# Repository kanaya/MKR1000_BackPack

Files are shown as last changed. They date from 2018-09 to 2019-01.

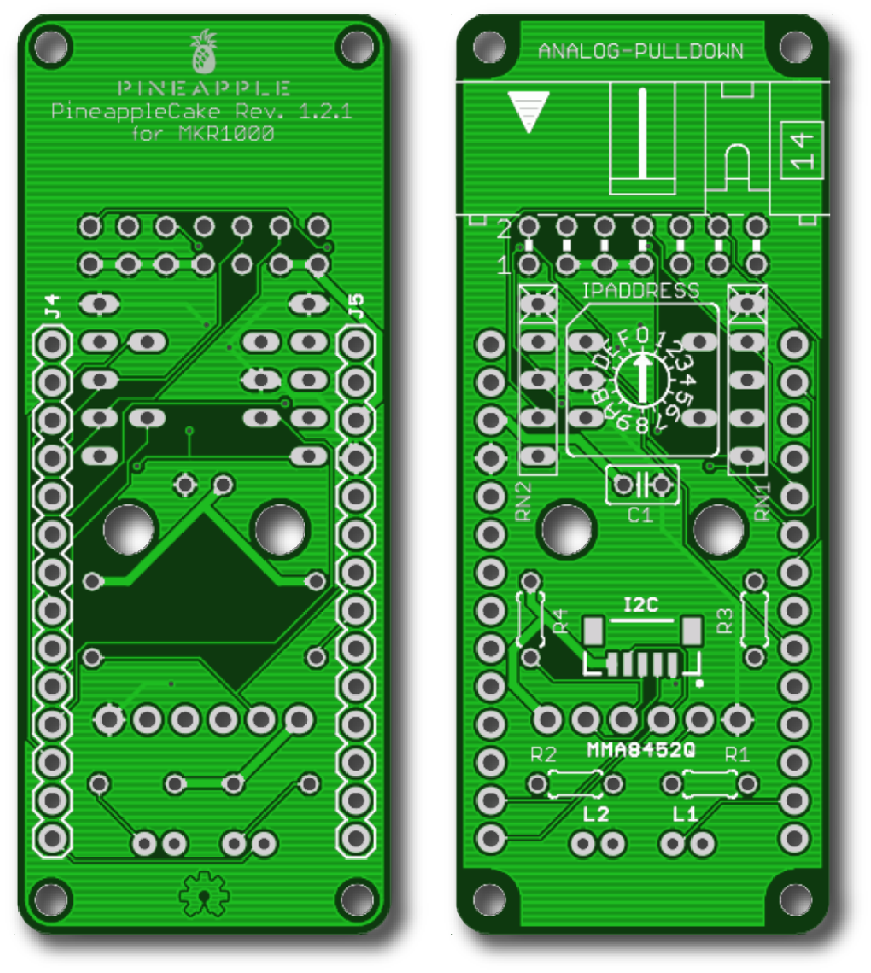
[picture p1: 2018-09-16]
doc/image/PineappleCake_1_2_1_material/5-PineappleCake_1_2_1_shadow.png

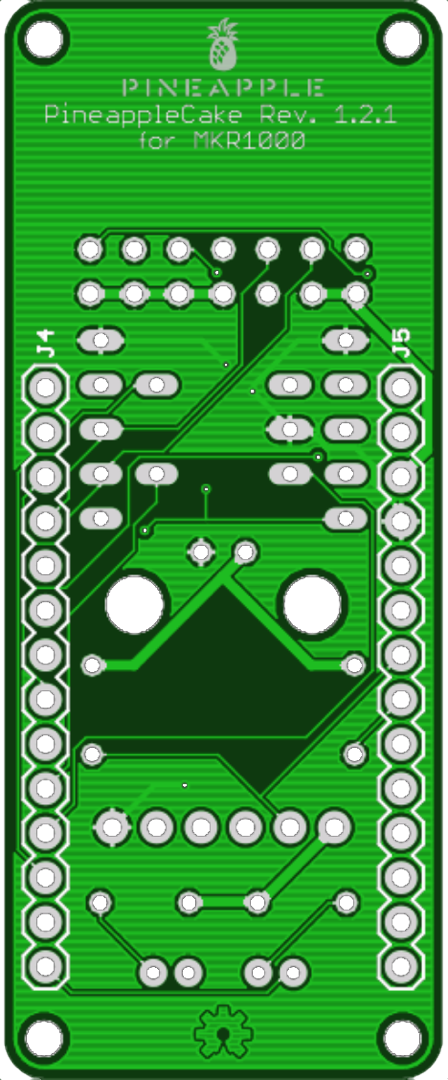
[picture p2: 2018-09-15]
doc/image/PineappleCake_1_2_1_material/3-PineappleCake_1_2_1-HD.png

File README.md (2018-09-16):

# PineappleCake

PineappleCake is a set of add-on board and software for [Arduino MKR1000](https://store.arduino.cc/usa/arduino-mkr1000) series for attaching analog sensors. Coupled with MKR1000, PineappleCake can read up-to seven physical sensors and send the values via HTTP on WiFi.

You can also attach [triple-axis accelerometer](https://www.sparkfun.com/products/12756) on PineappleCake. The acceleration data can be accessible via wireless HTTP connection.

And one more thing, you can control a couple of LEDs also via wireless HTTP connection.

You can change the IP address of multiple PineappleCakes by using attached rotary switch so that you’ll never need to modify the source code for just changing the addresses.

PineappleCake also offers missing [I2C connector (+5V, D7, SCL, SDA, GND)](https://store.arduino.cc/usa/arduino-mkrzero) found in other MKR series (e.g. [MKR ZERO](https://store.arduino.cc/usa/arduino-mkrzero)).

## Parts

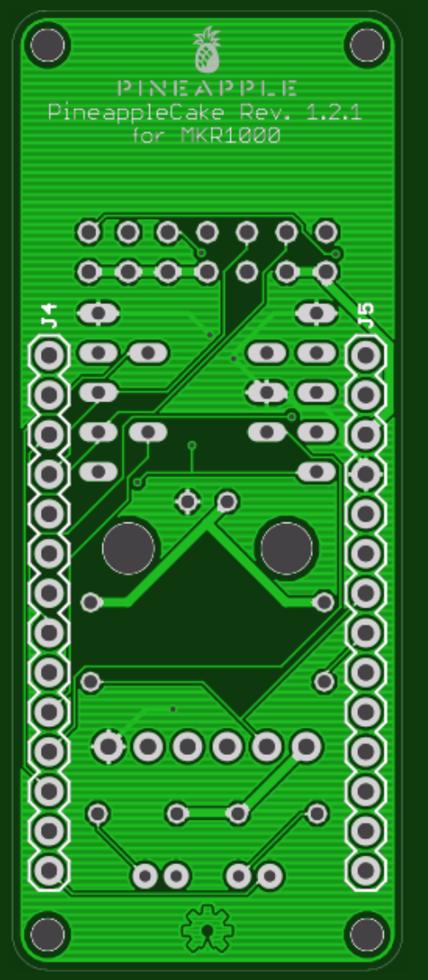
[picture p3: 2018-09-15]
doc/image/PineappleCake_1_2_1_material/0-PineappleCake_1_2_1_screenshot.png

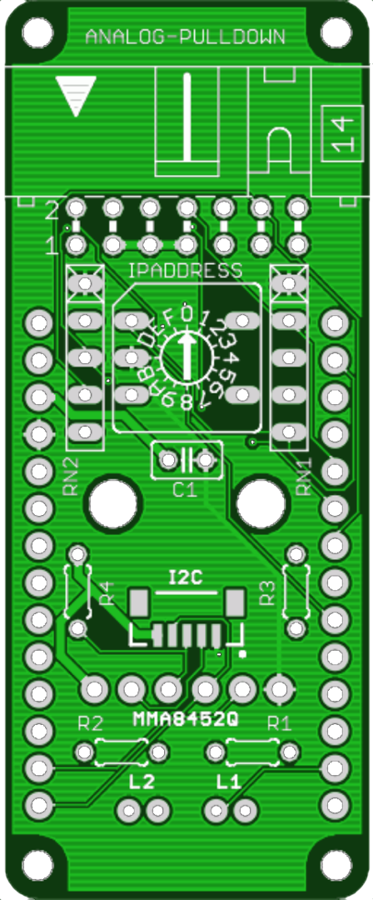
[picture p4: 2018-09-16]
doc/image/PineappleCake_1_2_1_back_material/3-PineappleCake_1_2_1_back-HD.png

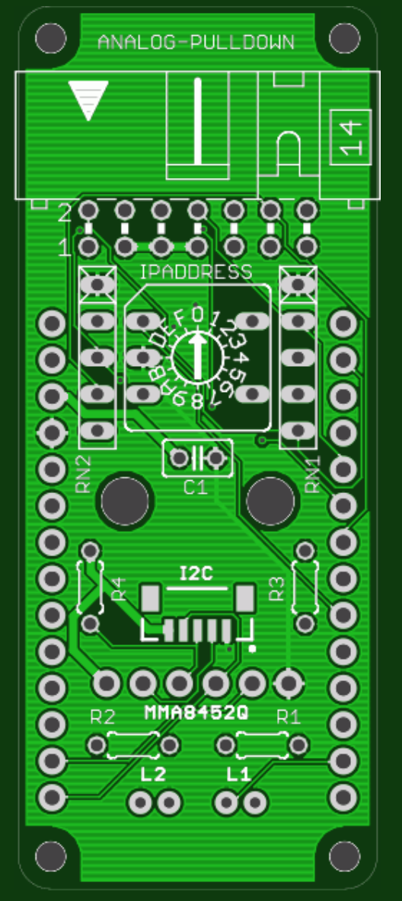
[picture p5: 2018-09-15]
doc/image/PineappleCake_1_2_1_back_material/0-PineappleCake_1_2_1_back_screenshot.png

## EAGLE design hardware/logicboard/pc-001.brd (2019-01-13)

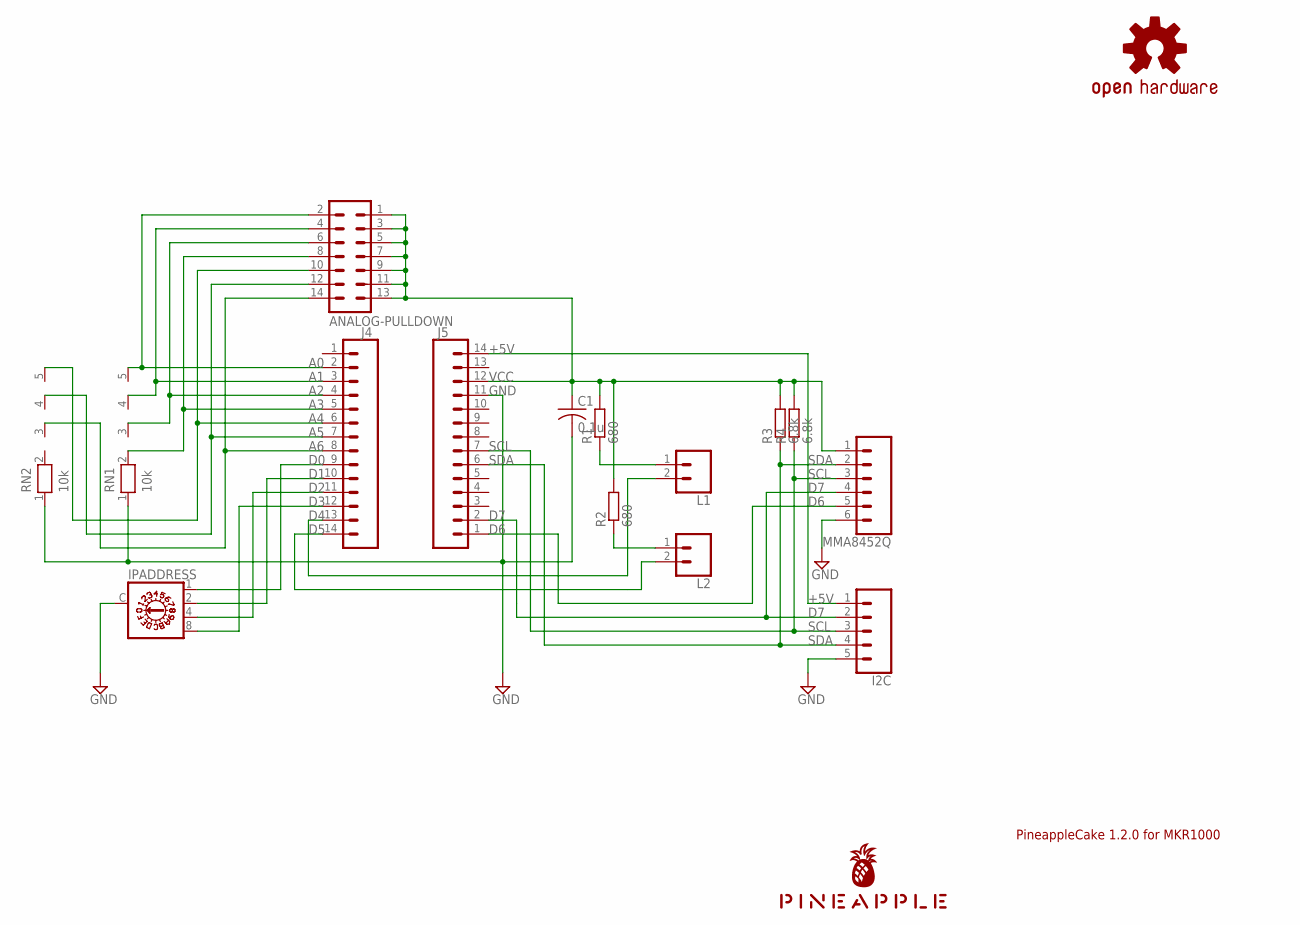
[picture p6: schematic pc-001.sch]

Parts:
ANALOG-PULLDOWN: ML14L
C1: 0.1u; C025-025X050
I2C: CONN_05SMD; 1X05_1MM
IPADDRESS: A1353HEX
J4, J5: DNP; 1X14
L1, L2: CONN_02-JST-2-PTH-NO_SILK; JST-2-PTH-NS
LOGO1: OSHW-LOGOS-COPPER; OSHW-LOGO-S_COPPER
MMA8452Q: CONN_06NO_SILK_FEMALE_PTH; 1X06_NO_SILK
R1, R2: 680; 0204/5
R3, R4: 6.8k; 0204/5
RN1, RN2: 10k; RN-5
U$1: PINEAPPLE450

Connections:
+5V: I2C.1, J5.14
A0: ANALOG-PULLDOWN.2, J4.2, RN1.5
A1: ANALOG-PULLDOWN.4, J4.3, RN1.4
A2: ANALOG-PULLDOWN.6, J4.4, RN1.3
A3: ANALOG-PULLDOWN.8, J4.5, RN1.2
A4: ANALOG-PULLDOWN.10, J4.6, RN2.5
A5: ANALOG-PULLDOWN.12, J4.7, RN2.4
A6: ANALOG-PULLDOWN.14, J4.8, RN2.3
D0: IPADDRESS.1, J4.9
D1: IPADDRESS.2, J4.10
D2: IPADDRESS.4, J4.11
D3: IPADDRESS.8, J4.12
D4: J4.13, L1.2
D5: J4.14, L2.2
D6: J5.1, MMA8452Q.5
D7: I2C.2, J5.2, MMA8452Q.4
GND: C1.2, I2C.5, IPADDRESS.C, J5.11, MMA8452Q.6, RN1.1, RN2.1
LED1A: L1.1, R1.1
LED2A: L2.1, R2.1
SCL: I2C.3, J5.7, MMA8452Q.3, R4.1
SDA: I2C.4, J5.6, MMA8452Q.2, R3.1
VCC: ANALOG-PULLDOWN.1, ANALOG-PULLDOWN.3, ANALOG-PULLDOWN.5, ANALOG-PULLDOWN.7, ANALOG-PULLDOWN.9, ANALOG-PULLDOWN.11, ANALOG-PULLDOWN.13, C1.1, J5.12, MMA8452Q.1, R1.2, R2.2, R3.2, R4.2

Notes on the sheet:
PineappleCake 1.2.0 for MKR1000

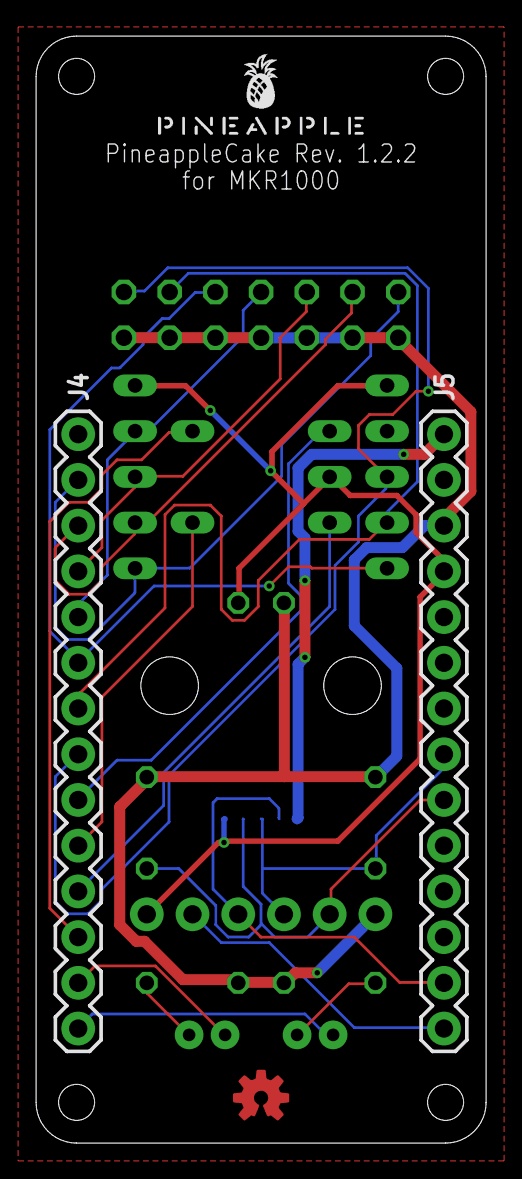
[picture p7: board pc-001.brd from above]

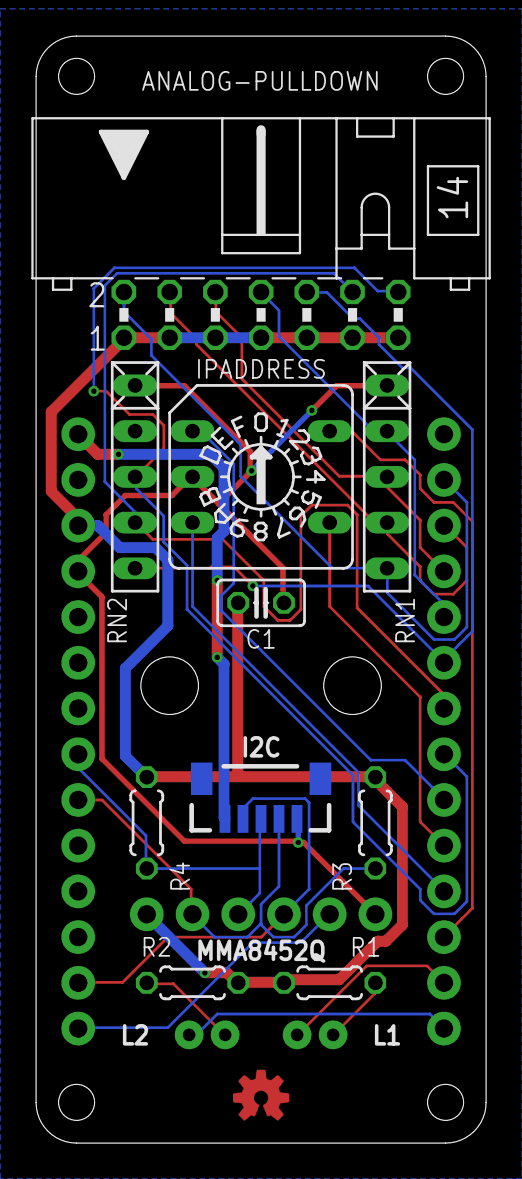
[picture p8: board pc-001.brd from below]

Board: 2 copper layers, 25.0 x 61.5 mm, 17 parts (13 on the bottom side), 22 nets.

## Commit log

2018-08-05 Imported MKR1000 board.
    [MKR1000.brd, MKR1000.sch]
2018-08-05 Removed everything but pinheaders.
    [MKR1000.brd, MKR1000.sch, mkr1000_backpack.brd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]
2018-08-05 Analog pins.
    [mkr1000_backpack.brd, mkr1000_backpack.sch]
2018-08-05 First try.
    [mkr1000_backpack.brd, mkr1000_backpack.sch]
2018-08-05 Second try. Looks good.
    [mkr1000_backpack.brd, mkr1000_backpack.sch]
2018-08-05 Backside mounting.
    [mkr1000_backpack.brd]
2018-08-05 Added encoder switch for selecting IP address.
    [mkr1000_backpack.brd, mkr1000_backpack.sch]
2018-08-05 Moved 10p MIL connector up by 1mm.
    [mkr1000_backpack.brd]
2018-08-06 LED ports and I2C port.
    [mkr1000_backpack.brd, mkr1000_backpack.sch]
2018-08-06 SparkFun Triple Axis Accelerometer Breakout - H3LIS331DL Ready.
    [mkr1000_backpack.brd, mkr1000_backpack.sch]
2018-08-06 Fixed position of pinheader.
    [mkr1000_backpack.brd, mkr1000_backpack.sch]
2018-08-11 Name change.
    [pc1000-001.brd, pc1000-001.sch]
2018-08-11 Filename change.
    [pc-001.brd, pc-001.sch]
2018-08-11 GND pattern.
    [pc-001.brd]
2018-08-11 OSHW logo.
    [pc-001.brd, pc-001.sch]
2018-08-13 Pineapple logo v2.
    [pc-001.brd, pc-001.sch]
2018-08-13 New pineapple logo.
    [pc-001.brd, pc-001.sch]
2018-08-14 Updated silk pattern.
    [pc-001.brd, pc-001.sch]
2018-08-14 Changed signal names.
    [pc-001.brd, pc-001.sch]
2018-08-14 Version number 1.0.0 -> 2.0.0.
    [pc-001.brd, pc-001.sch]
2018-08-17 Changed silk pattern of version number (1.2.0).
    [pc-001.brd]
2018-08-17 Moved "Analog" silk.
    [pc-001.brd]
2018-08-20 Changed Pineapple Logo from Vector-based to Bitmap-based.
    [pc-001.brd, pc-001.sch]
2018-08-21 OSHW logo (silk -> copper).
    [pc-001.brd, pc-001.sch]
2018-08-21 Flipped I2C connector.
    [pc-001.brd, pc-001.sch]
2018-08-21 Fixed error of version number on the schematic.
    [pc-001.sch]
2018-08-21 Flipped I2C connector (again).
    [pc-001.brd]
2018-08-22 Changed font size of silk patterns.
    [pc-001.brd]
2018-09-15 Route update.
    [pc-001.brd]
2018-09-16 1st pin of I2C connector now has 5V supply, not 3.3V.
    [pc-001.brd, pc-001.sch]
2018-09-21 Hotfix. I2C connector is now connected to +5V, not +3.3V (Vcc).
    [pc-001.brd, pc-001.sch]
2018-10-15 Fixed wrong connection to MMA8452Q.
    [pc-001.brd, pc-001.sch]
2018-10-26 Fixed positioning of MMA8452Q.
    [pc-001.brd]
2019-01-13 Fixed connection of SDA.
    [pc-001.brd, pc-001.sch]
2019-01-13 Fixed revision number on the board.
    [pc-001.brd]

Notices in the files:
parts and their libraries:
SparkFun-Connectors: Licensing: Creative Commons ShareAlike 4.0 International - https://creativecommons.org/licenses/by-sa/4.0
